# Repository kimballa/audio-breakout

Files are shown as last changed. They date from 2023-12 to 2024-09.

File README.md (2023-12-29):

Breadboard audio breakout
=========================

This board is intended to sit next to a pair of breadboards and plug into the power bus rows and the
first few columns of each breadboard. Measurements were taken on Adafruit breadboards.

Power
-----

Power bus rows are filled with +12V, GND, and -12V from the onboard power header.
* This takes a molex 3-pin MicroFit 3.0 cable from a GS-101-PWR.
* There is a power switch, and LEDs to show you when it's engaged.
* There are jumper headers that the power flows through before accessing your board.
  * Close these with SPC02SYAN shunt jumpers to let the power flow.
  * Or hook your ammeter here to measure current consumption precisely.
  * The onboard opamp and LEDs are upstream of the jumpers and will not be included 
    in your current measurements.
* There is also a 3-pin MicroFit 3.0 header to daisy-chain a cable to a module under test,
  for current measurement purposes.

Leveling feet
-------------

The two mounting holes on the outboard edge of the PCB are sized for an M3 screw. A 20mm machine
screw with an integral end-stop like JLCPCB Mechatronics' EKLF-W-P12-M3-L20 can be used to balance
this edge of the board so that it lies flat when you adjust potentiometers or plug in cables.

Reference voltages
-------------------

There are two reference voltages generated onboard and brought out to pins, at 8.0V and 6.0V. Use
the two trimpots on the bottom of the PCB to calibrate these.

Jacks
-----

There are six jacks, `IO1..IO4`, `OUT1`, and `OUT2`. 

The I/O jacks are general purpose and bidirectional. Shields are attached to GND via 1M resistance.
The tip goes to the labeled pin on the breadboard.

OUT1 and OUT2 are unity buffered by an opamp with 220kOhm input impedence. These are intended to
drive a signal to a speaker or other external system. The TL074H opamp is specified to deliver at
least 25mA before losing voltage fidelity. The shields for OUT1 and OUT2 are directly connected to
GND. 

There are also header pins on the top of the board for accessing OUT1 and OUT2 on a 'scope or
multimeter.

Pots
----

There are four PTV09 potentiometers, two at 100kOhm and two at 10kOhm resistance. All three pins of
each pot are brought out to the breadboard. Pin numbers are indicated with one to three dots.

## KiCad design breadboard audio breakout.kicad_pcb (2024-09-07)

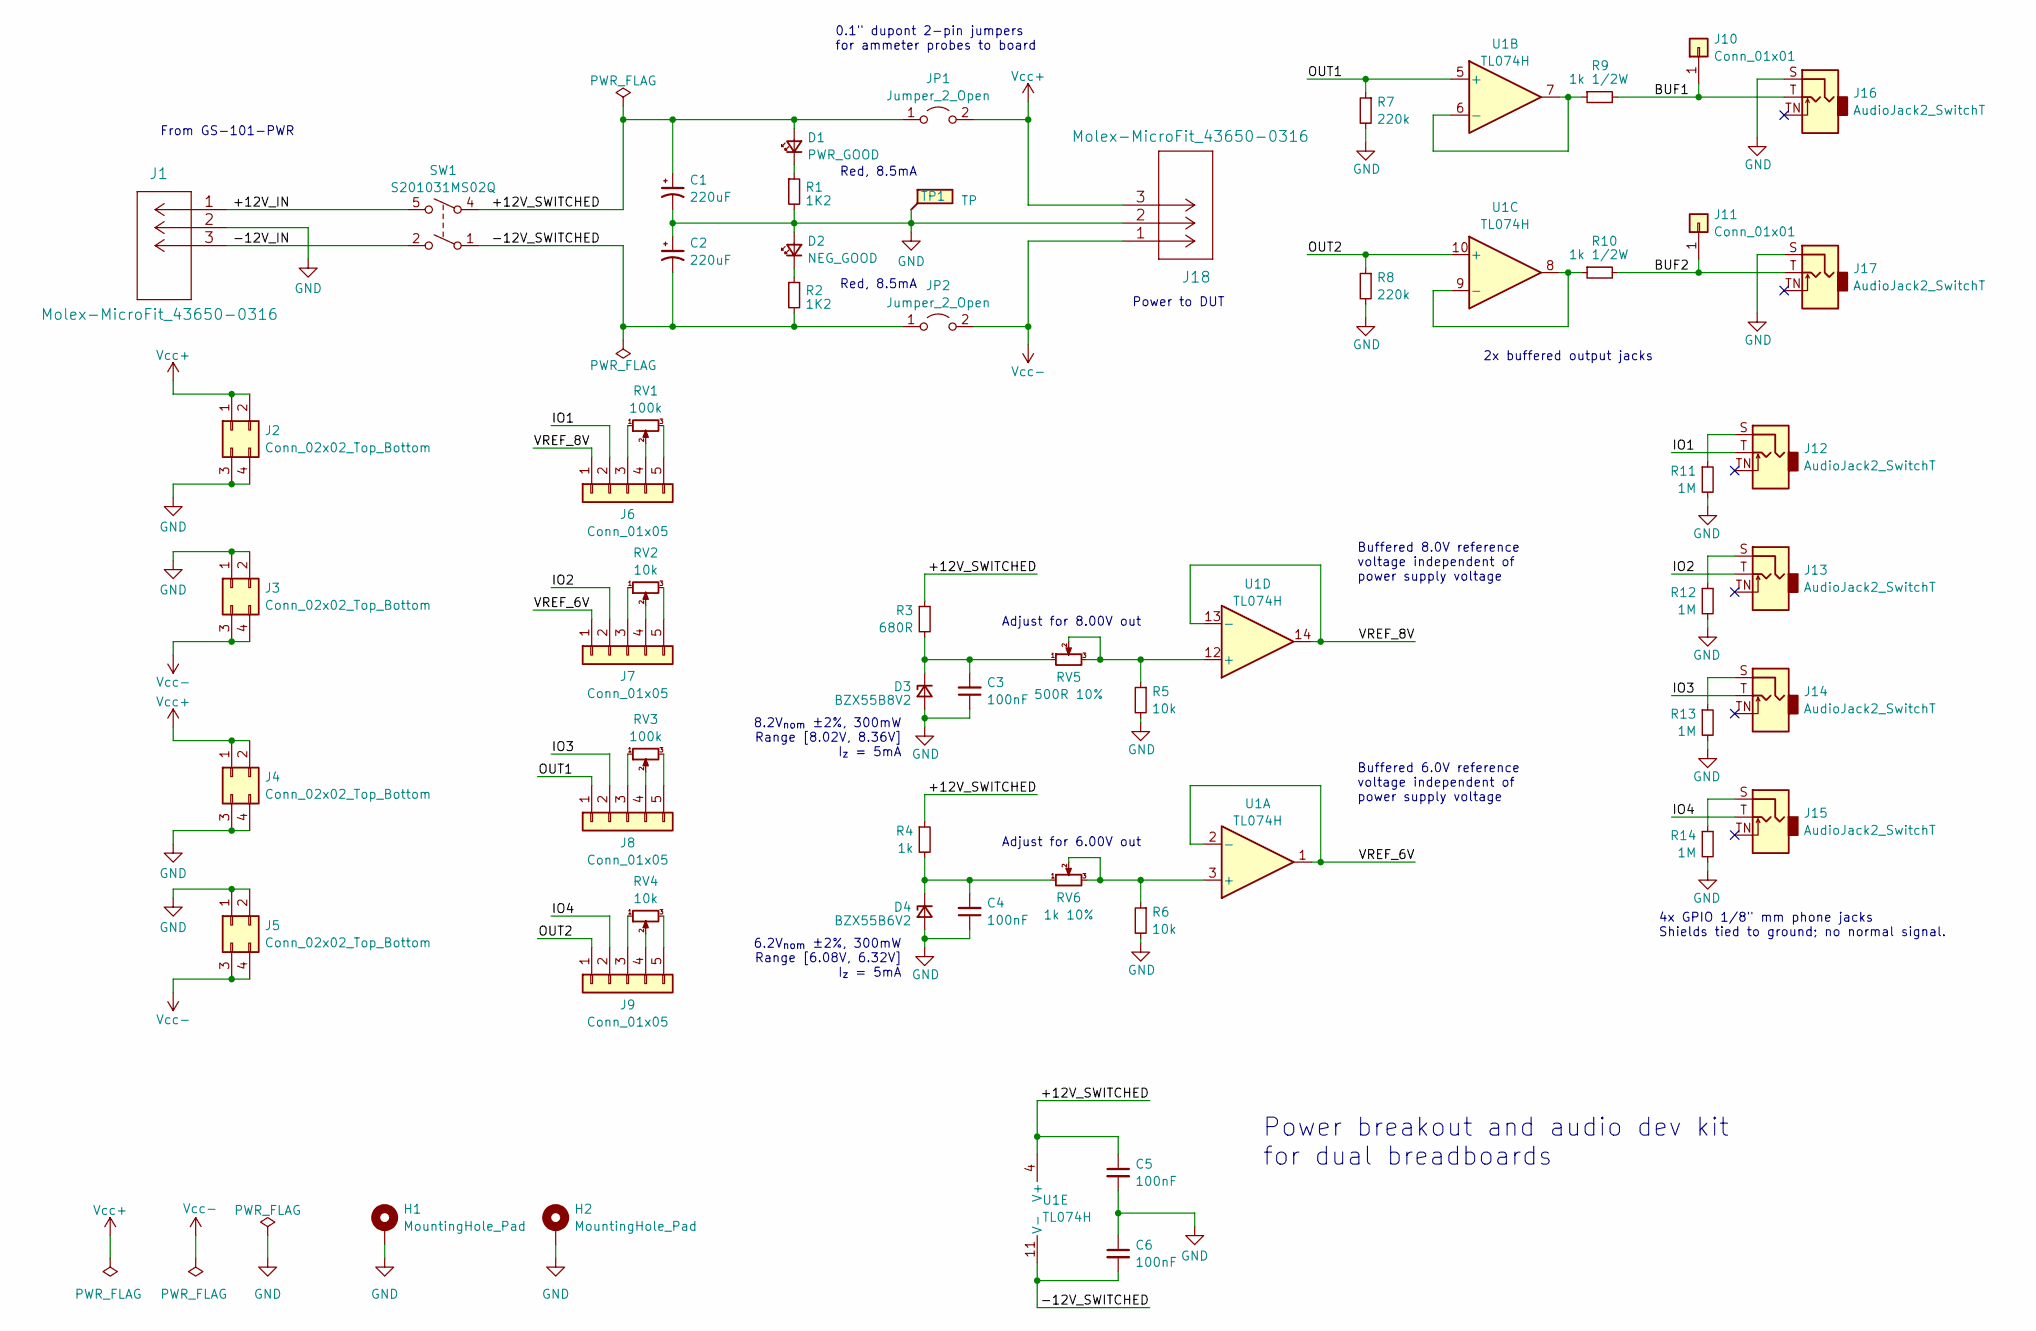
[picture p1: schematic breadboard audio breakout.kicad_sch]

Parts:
C1, C2: 220uF; CP_Radial_D10.0mm_P5.00mm; MPN ESW227M035AH9AA
C3, C4, C5, C6: 100nF; C_0805_2012Metric_Pad1.18x1.45mm_HandSolder; MPN CL21B104KBFNNNE
D1: PWR_GOOD; LED_D5.0mm_SilkFix; MPN LTL-4223
D2: NEG_GOOD; LED_D5.0mm_SilkFix; MPN LTL-4223
D3: BZX55B8V2; D_SOD-323_HandSoldering; MPN MM3Z8V2ST1G
D4: BZX55B6V2; D_SOD-323_HandSoldering; MPN MM3Z6V2ST1G
H1, H2: MountingHole_Pad; MountingHole_3.3mm_M3_Full_Standoff_Size
J1, J18: Molex-MicroFit_43650-0316; Molex-Microfit-43650-0316; MPN 436500316
J2, J3, J4, J5: Conn_02x02_Top_Bottom; PinHeader_2x02_P2.54mm_Vertical; MPN 67997-400HLF
J6, J7, J8, J9: Conn_01x05; PinHeader_1x05_P2.54mm_Vertical; MPN 5-146850-1
J10, J11: Conn_01x01; PinHeader_1x01_P2.54mm_Vertical; MPN 5-146850-1
J12, J13, J14, J15, J16, J17: AudioJack2_SwitchT; Schurter-4832.2211; MPN 4832.2211
JP1, JP2: Jumper_2_Open; PinHeader_1x02_P2.54mm_Vertical; MPN 5-146850-1
R1, R2: 1K2; R_0805_2012Metric_Pad1.20x1.40mm_HandSolder; MPN RMCF0805FT1K20
R3: 680R; R_0805_2012Metric_Pad1.20x1.40mm_HandSolder; MPN RMCF0805FT680R
R4: 1k; R_0805_2012Metric_Pad1.20x1.40mm_HandSolder; MPN RMCF0805FT1K00
R5, R6: 10k; R_0805_2012Metric_Pad1.20x1.40mm_HandSolder; MPN RMCF0805FT10K0
R7, R8: 220k; R_0805_2012Metric_Pad1.20x1.40mm_HandSolder; MPN RMCF0805FT220K
R9, R10: 1k 1/2W; R_1206_3216Metric_Pad1.30x1.75mm_HandSolder; MPN RNCP1206FTD1K00
R11, R12, R13, R14: 1M; R_0805_2012Metric_Pad1.20x1.40mm_HandSolder; MPN RMCF0805FT1M00
RV1, RV3: 100k; Pot_Bourns_PTV09_vert_3dModel; MPN PTV09A-4025F-B104
RV2, RV4: 10k; Pot_Bourns_PTV09_vert_3dModel; MPN PTV09A-4025F-B103
RV5: 500R 10%; Pot_Bourns_3362P; MPN 3362P-1-501LF
RV6: 1k 10%; Pot_Bourns_3362P; MPN 3362P-1-102LF
SW1: S201031MS02Q; CK_SPDT_S201031MS02Q; MPN S201031MS02Q
TP1: TP; TP_HeaderPin_P2.54mm_round
U1: TL074H; TI_SOIC_D_R-PDSO-G14; MPN TL074HIDR

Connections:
/+12V_IN: J1.1, SW1.5
/+12V_SWITCHED: C1.1, C5.1, D1.2 (A), JP1.1 (A), R3.1, R4.1, SW1.4, U1.4 (V+)
/-12V_IN: J1.3, SW1.2
/-12V_SWITCHED: C2.2, C6.2, JP2.1 (A), R2.2, SW1.1, U1.11 (V-)
/BUF1: J10.1, J16.T, R9.2
/BUF2: J11.1, J17.T, R10.2
/IO1: J6.2, J12.T
/IO2: J7.2, J13.T
/IO3: J8.2, J14.T
/IO4: J9.2, J15.T
/OUT1: J8.1, R7.1, U1.5 (+)
/OUT2: J9.1, R8.1, U1.10 (+)
/VREF_6V: J7.1, U1.1, U1.2 (-)
/VREF_8V: J6.1, U1.13 (-), U1.14
GND: C1.2, C2.1, C3.1, C4.1, C5.2, C6.1, D2.2 (A), D3.2 (A), D4.2 (A), H1.1, H2.1, J1.2, J2.3, J2.4, J3.1, J3.2, J4.3, J4.4, J5.1, J5.2, J16.S, J17.S, J18.2, R1.2, R5.2, R6.2, R7.2, R8.2, R11.2, R12.2, R13.2, R14.2, TP1.1
unnamed: D1.1 (K), R1.1
unnamed: D2.1 (K), R2.1
unnamed: C3.2, D3.1 (K), R3.2, RV5.1
unnamed: C4.2, D4.1 (K), R4.2, RV6.1
unnamed: J6.3, RV1.1
unnamed: J6.4, RV1.2
unnamed: J6.5, RV1.3
unnamed: J7.3, RV2.1
unnamed: J7.4, RV2.2
unnamed: J7.5, RV2.3
unnamed: J8.3, RV3.1
unnamed: J8.4, RV3.2
unnamed: J8.5, RV3.3
unnamed: J9.3, RV4.1
unnamed: J9.4, RV4.2
unnamed: J9.5, RV4.3
unnamed: J12.S, R11.1
unnamed: J13.S, R12.1
unnamed: J14.S, R13.1
unnamed: J15.S, R14.1
unnamed: R6.1, RV6.2, RV6.3, U1.3 (+)
unnamed: R9.1, U1.6 (-), U1.7
unnamed: R10.1, U1.8, U1.9 (-)
unnamed: R5.1, RV5.2, RV5.3, U1.12 (+)
Vcc+: J2.1, J2.2, J4.1, J4.2, J18.3, JP1.2 (B)
Vcc-: J3.3, J3.4, J5.3, J5.4, J18.1, JP2.2 (B)

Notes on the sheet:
8.2V_{nom} ±2%, 300mW Range [8.02V, 8.36V] I_{z} = 5mA
0.1" dupont 2-pin jumpers for ammeter probes to board
Buffered 8.0V reference voltage independent of power supply voltage
6.2V_{nom} ±2%, 300mW Range [6.08V, 6.32V] I_{z} = 5mA
Adjust for 6.00V out
Red, 8.5mA
Power breakout and audio dev kit for dual breadboards
2x buffered output jacks
From GS-101-PWR
Buffered 6.0V reference voltage independent of power supply voltage
4x GPIO 1/8" mm phone jacks Shields tied to ground; no normal signal.
Power to DUT
Adjust for 8.00V out

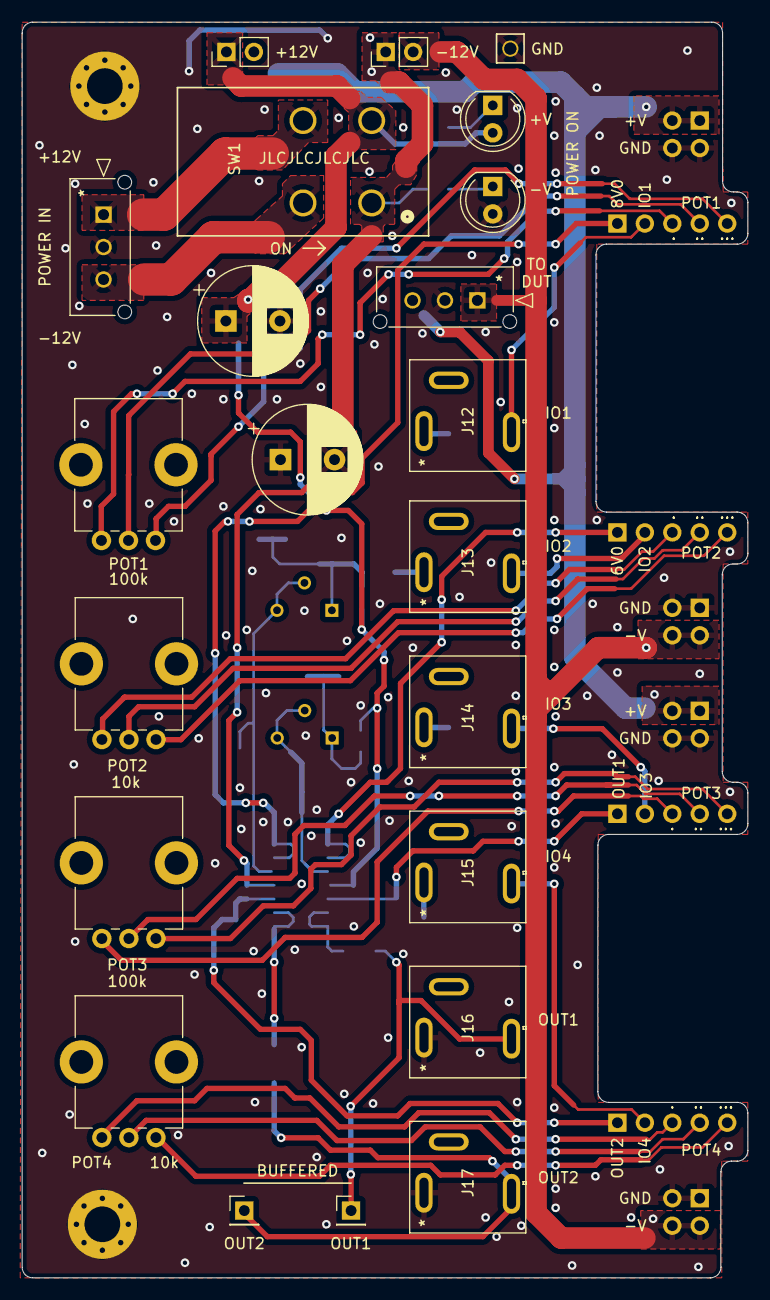
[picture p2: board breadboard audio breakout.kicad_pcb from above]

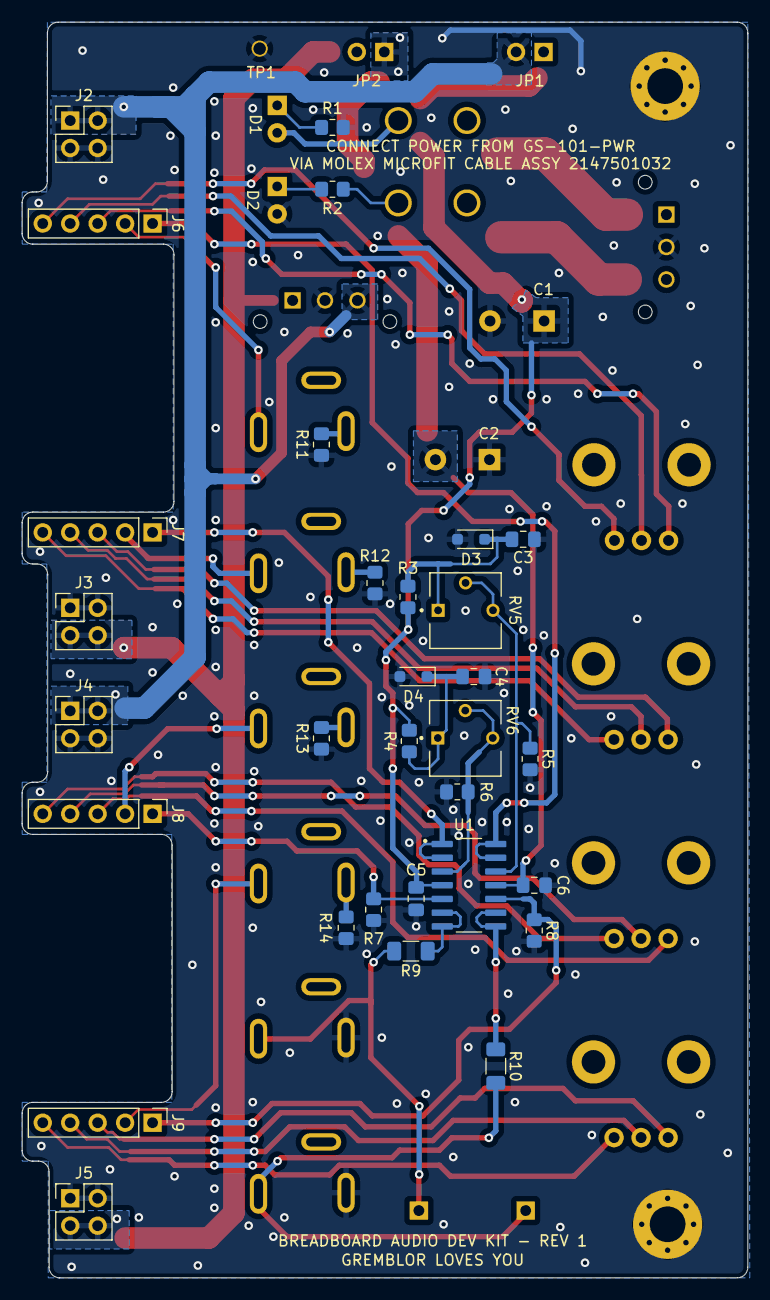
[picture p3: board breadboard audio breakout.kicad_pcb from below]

Board: 2 copper layers, 67.1 x 116.2 mm, 55 parts (31 on the bottom side), 41 nets.

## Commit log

2023-12-29 Add project files.
    [breadboard audio breakout.kicad_pcb, breadboard audio breakout.kicad_sch]
2023-12-29 Update PCB file with gerber generation config.
    [breadboard audio breakout.kicad_pcb]
2023-12-29 Add v1.0 RTM gerbers.
    [breadboard audio breakout-B_Cu.gbl, breadboard audio breakout-B_Mask.gbs, breadboard audio breakout-B_Paste.gbp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]
2024-09-07 Update to KiCad 8.0 format.
    [breadboard audio breakout.kicad_pcb, breadboard audio breakout.kicad_sch]
